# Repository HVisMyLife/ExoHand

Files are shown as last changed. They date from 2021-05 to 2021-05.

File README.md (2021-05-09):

# ExoHand
Exoskeleton build repo

IMG_4078v2

Video: https://youtu.be/7lpqHJdtj9U

I have decided few weeks ago, to design and make a prototype of an exoskeleton that would help people with disabilities in their normal functioning.
It was assumed that the designed device will support the rehabilitation of patients after elbow and hand injuries by mechanically "powering" these joints.
The design allows it to be controlled by a button in the palm of your hand, or by pre-programmed sequences of movements. It is also possible to adjust the speed via a potentiometer on the electronics housing.

List of parts:
- 12v 775 DC motor,
- MG996R servo motor,
- Blue Pill,
- 10k potentiometer,
- H 43A bridge based on half BTS7960 bridges,
- Matrix 4x4 flexible keyboard,
- 1.5mm2 cables,
- LiPo 2s 3Ah battery,
- aluminum angle 20mmx10mm,
- racks for elbow gears,
- hoops fixing the exoskeleton to the hand,
- printed elements of the hand mechanism,
- a cotton glove,
- M5 screws,
- M3 screws,
- PlastSpaw PLA 1.75mm filament

Electronic diagram:
Schematic_ExoArm

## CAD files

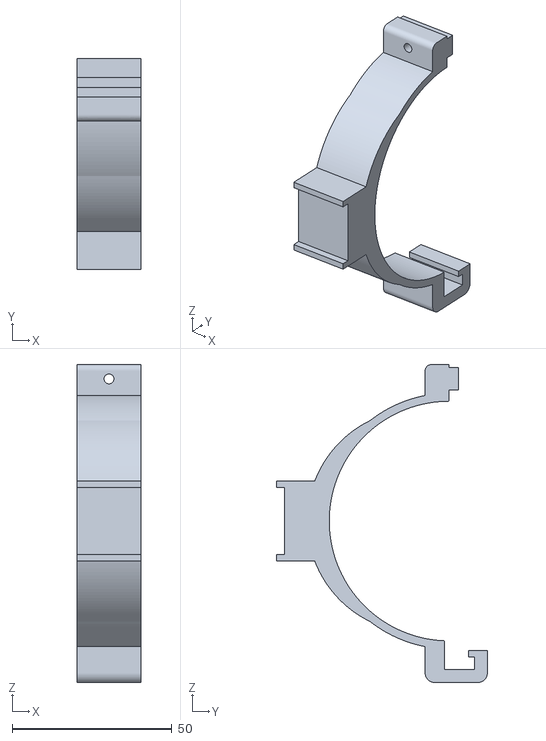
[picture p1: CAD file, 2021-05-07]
Exoskeleton/Arm/Rings/3B.stl
20.0 x 66.0 x 99.5

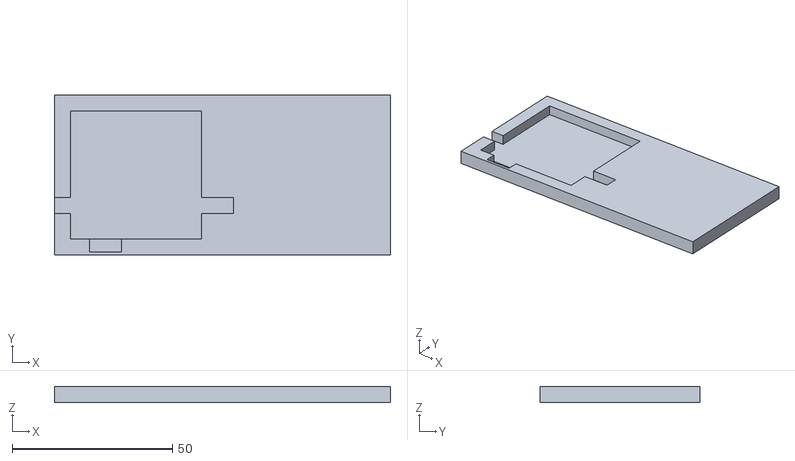
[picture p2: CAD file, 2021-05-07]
Exoskeleton/Arm/Table.stl
105.0 x 50.0 x 5.00

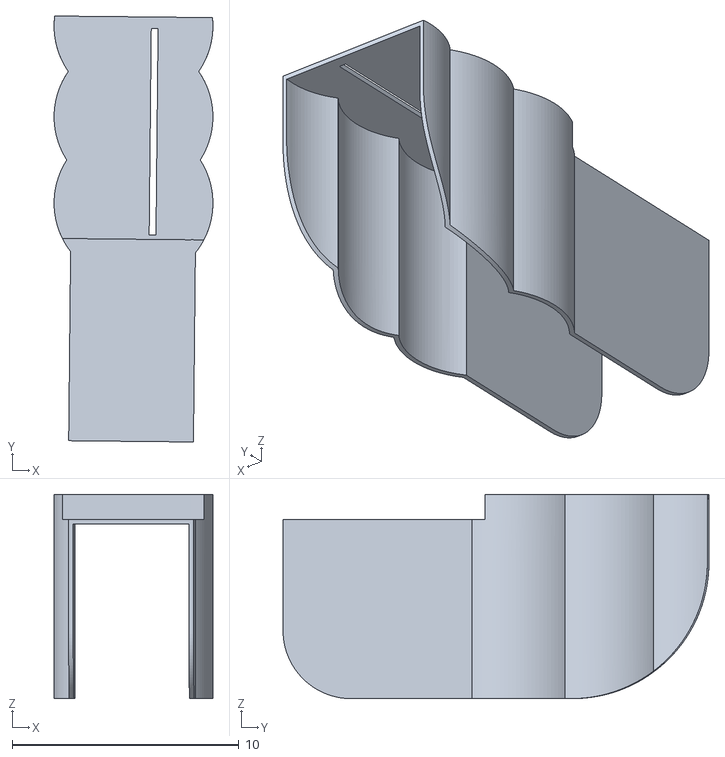
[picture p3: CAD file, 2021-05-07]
Exoskeleton/Case.stl
7.00 x 18.8 x 9.00

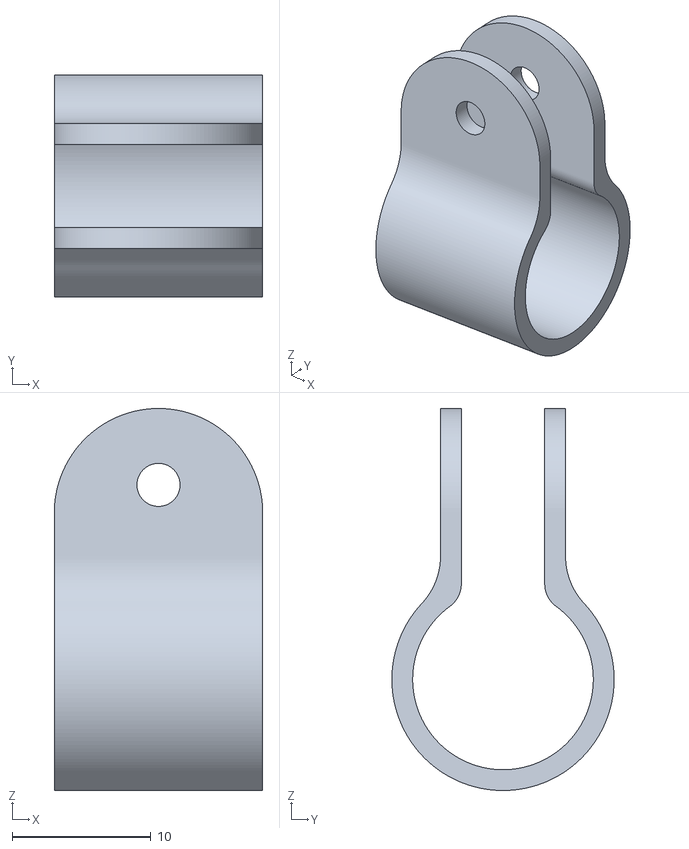
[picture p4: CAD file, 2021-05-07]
Exoskeleton/Hand/Rings/13.stl
15.0 x 16.0 x 27.5

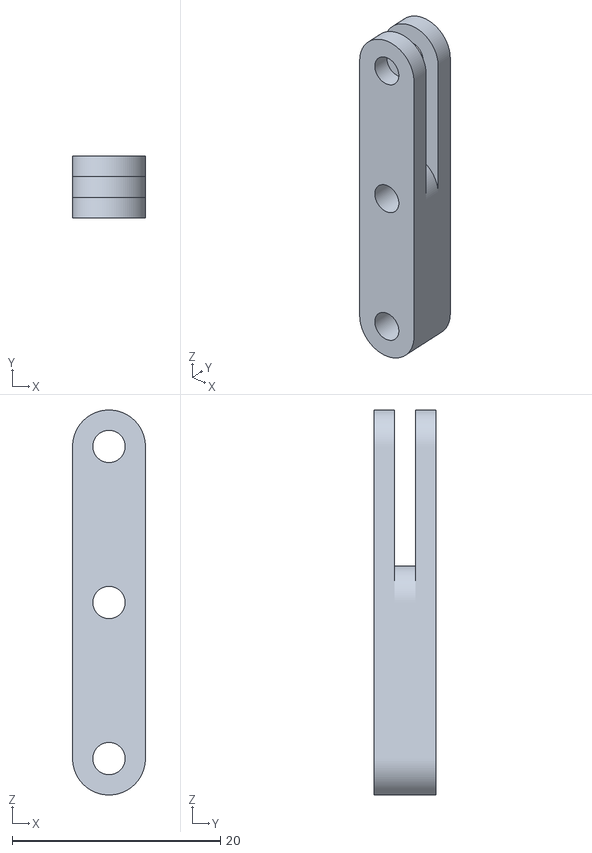
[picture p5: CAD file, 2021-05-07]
Exoskeleton/Hand/StickMid.stl
7.00 x 6.00 x 37.0

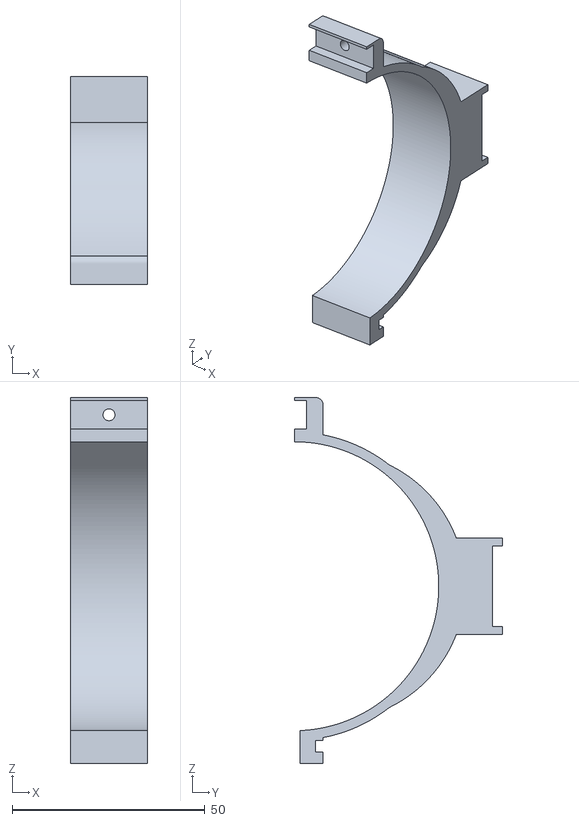
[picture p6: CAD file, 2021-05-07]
Exoskeleton/Arm/Rings/3A.stl
20.0 x 53.9 x 95.0

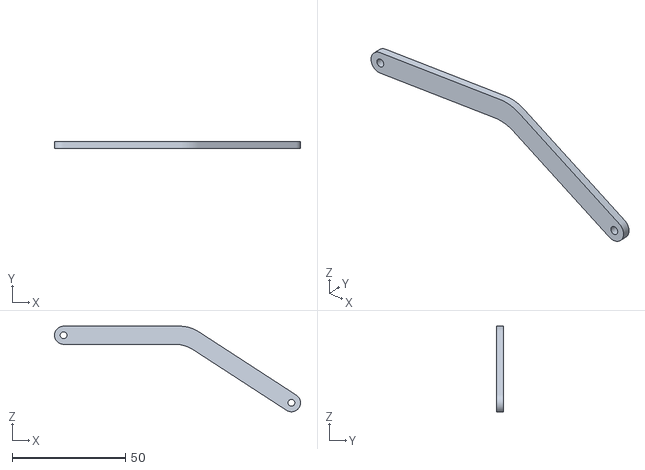
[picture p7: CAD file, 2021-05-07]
Exoskeleton/Hand/BigJoint.stl
108.8 x 3.00 x 37.8

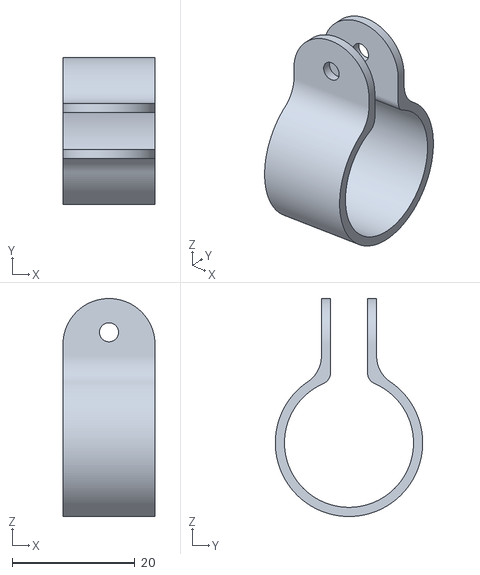
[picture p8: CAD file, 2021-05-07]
Exoskeleton/Hand/Rings/21.stl
15.0 x 24.0 x 35.5

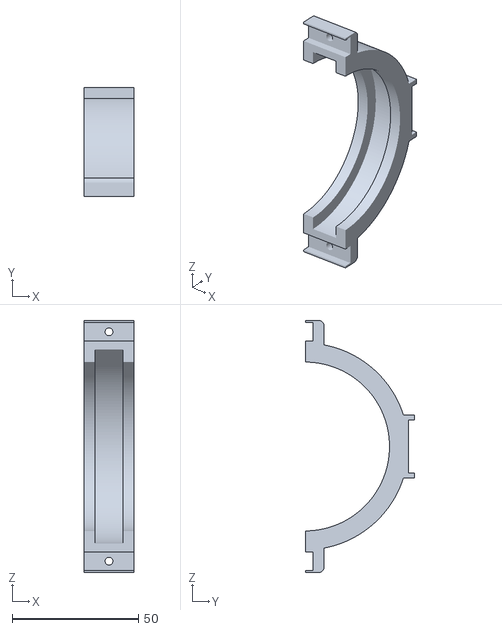
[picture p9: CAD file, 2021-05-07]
Exoskeleton/Arm/Rings/1A.stl
20.0 x 43.4 x 100.0

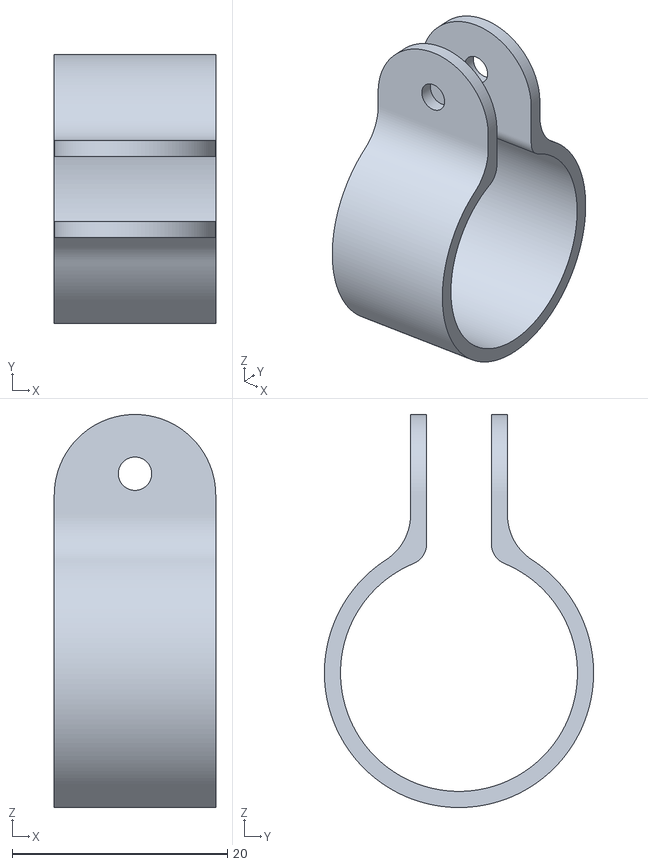
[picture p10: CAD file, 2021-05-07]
Exoskeleton/Hand/Rings/22.stl
15.0 x 25.0 x 36.5

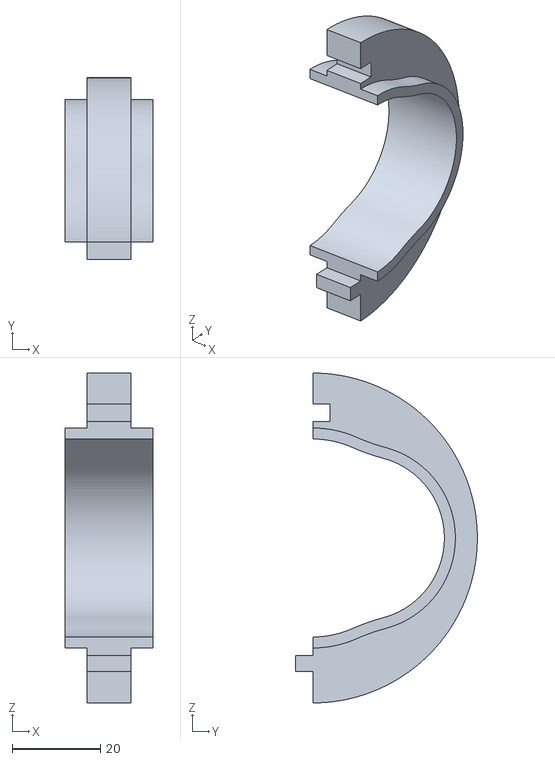
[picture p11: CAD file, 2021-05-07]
Exoskeleton/Arm/Rings/1C.stl
20.0 x 41.3 x 75.0

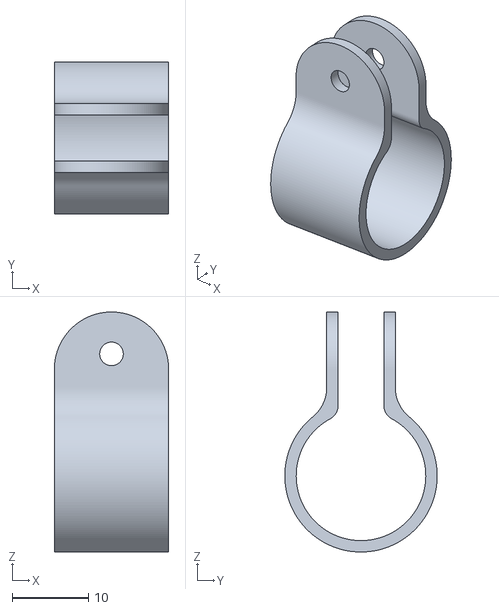
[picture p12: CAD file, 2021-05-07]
Exoskeleton/Hand/Rings/17.stl
15.0 x 20.0 x 31.5

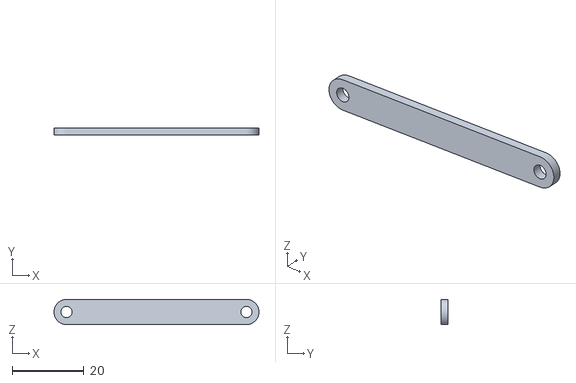
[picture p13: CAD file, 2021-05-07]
Exoskeleton/Hand/StickJoint.stl
57.0 x 2.00 x 7.00

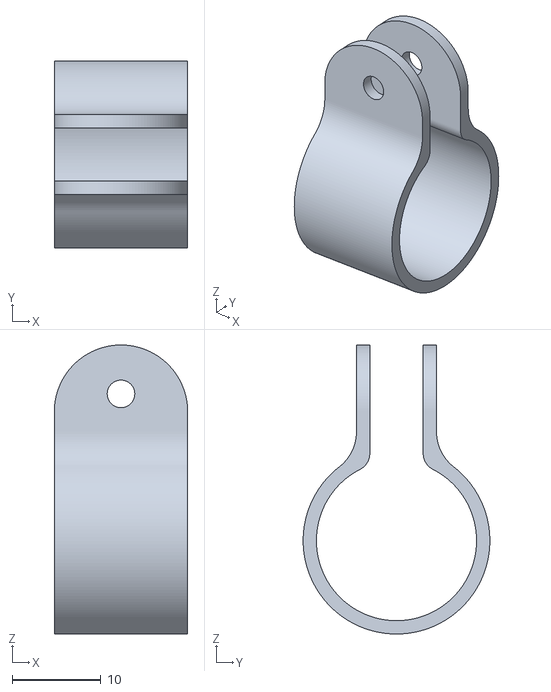
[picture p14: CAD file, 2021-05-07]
Exoskeleton/Hand/Rings/18.stl
15.0 x 21.0 x 32.5

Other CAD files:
Exoskeleton/Arm/Rings/1D.stl
Exoskeleton/Hand/StickTip.stl
Exoskeleton/Arm/Rings/2B.stl
Exoskeleton/Hand/Rings/20.stl
Exoskeleton/Arm/Rings/1B.stl
Exoskeleton/Arm/Rings/2A.stl
Exoskeleton/Arm/Rings/4A.stl
Exoskeleton/Arm/Rings/4B.stl
Exoskeleton/Hand/Bolt.stl
Exoskeleton/Hand/Rings/12.stl
Exoskeleton/Hand/Rings/14.stl
Exoskeleton/Hand/Rings/15.stl
Exoskeleton/Hand/Rings/16.stl
Exoskeleton/Hand/Rings/19.stl

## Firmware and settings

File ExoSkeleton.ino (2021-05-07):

#include <Servo.h>

int RPWM = PB9;
int LPWM = PB8;
int L_EN = PB3;
int R_EN = PB4;
int servo = PA8;

Servo hand;
float pos, armPosition;
float speedMove, speedMove2;
float pwmSig;

int pushButton = PB14;
int pot = PB1;
int potPos = PB0;
int keyPad = PA7;

int stage = 0;

int key = 0;
char keyCharBuffer;
char keyChar;
bool keyPadUsage = false, keyStartInput = false, keyStopInput = false;


bool dir, enMove = false, input;

long long unsigned int startTime, closeTime, startTime2, openTime, moveTime, keyStopTime, keyStartTime, moveDeltaTime;

void WriteMove();
void ReadPush();
void ReadKey();

void setup() {
  // put your setup code here, to run once:
  pinMode(PB9, OUTPUT);
  pinMode(PB8, OUTPUT);
  pinMode(PB3, OUTPUT);
  pinMode(PB4, OUTPUT);
  pinMode(PC13, OUTPUT);
  pinMode(pushButton, INPUT_PULLUP);
  pinMode(pot, INPUT);
  pinMode(potPos, INPUT);
  pinMode(keyPad, INPUT);

  hand.attach(servo);

  dir = true;

  digitalWrite(R_EN,HIGH);
  digitalWrite(L_EN,HIGH);
  
  delay(250);
  Serial.begin(115200);
  }

void loop() {
  WriteMove();
  ReadKey();
  ReadPush();
  
  delay(1);
}

void WriteMove()
{
  armPosition = analogRead(potPos);
  if (armPosition > 3000) armPosition = 3000;
  if (armPosition < 1500) armPosition = 1500;
  armPosition = map(armPosition, 1500, 3000, 1024, 0);
  Serial.println(armPosition);
  //Serial.print(" || ");
  //Serial.println(pos);
  speedMove = map(analogRead(pot), 0, 4096, 0, 1000);

  pwmSig = armPosition - pos;
  if (pwmSig < 0) pwmSig = -pwmSig;
  if (pwmSig > 255) pwmSig = 255;
  speedMove2 = map(speedMove, 0, 1000, 400, 75);
  speedMove2 /= 100;
    
  if(enMove && armPosition > 0 && dir) 
  {
    if( micros() - moveDeltaTime > speedMove) { pos -= speedMove2; moveDeltaTime = micros();}
    if (pos < 0) pos = 0;
    hand.write(map(pos, 0, 1024, 0, 255));
    if(armPosition > pos + 25) {analogWrite(LPWM, pwmSig); analogWrite(RPWM, 0);}
    else if(armPosition < pos - 25) {analogWrite(LPWM, 255); analogWrite(RPWM, 255);}
    else {analogWrite(LPWM, 0);analogWrite(RPWM, 0);}
  }
  else if (enMove && armPosition < 1024 && !dir) 
  {
    if( micros() - moveDeltaTime > speedMove ) { pos += speedMove2; moveDeltaTime = micros();}
    if (pos > 1024) pos = 1024;
    hand.write(map(pos, 0, 1024, 0, 255));
    if(armPosition < pos - 25) {analogWrite(LPWM, 0); analogWrite(RPWM, pwmSig);}
    else if(armPosition > pos + 25) {analogWrite(LPWM, 255); analogWrite(RPWM, 255);}
    else {analogWrite(LPWM, 0);analogWrite(RPWM, 0);}
  }
  else
  {
    analogWrite(LPWM, 0);
    analogWrite(RPWM, 0);
  }

  //if ( armPosition <= 50 && dir && enMove || armPosition >= 1998 && !dir && enMove ) {stage = 0; enMove = false;}
}

void ReadPush()
{
  input = digitalRead(pushButton);
  digitalWrite(PC13, input);
   
  switch (stage){
    case 0:
      if ( !input ) {startTime = millis(); stage = 1;}
    break;
    case 1:
      if (input && millis() - startTime < 100) stage = 0;
      else if (!input && millis() - startTime >= 100) stage = 2;
    break;
    case 2:
      if (input) {startTime2 = millis(); stage = 3; }
    break;
    case 3:
      if (!input && millis() - startTime2 < 50) stage = 2;
      else if (!input && millis() - startTime2 >= 50) stage = 4;                              //double
      else if (input && millis() - startTime2 >= 750) { stage = 5; enMove = true; dir = false; moveTime = millis(); moveDeltaTime = micros();}   //single
    break;
    case 4:
      if (input) { stage = 5; enMove = true; dir = true; moveTime = millis(); moveDeltaTime = micros();}
    break;
    case 5:
      if (!input && millis() - moveTime > 25) {stage = 6; enMove = false;}
    break;
    case 6:
      if (input) stage = 0;
    break;
    default:
      
    break;
  }
}

void ReadKey()
{
  key = ((key * 19) + analogRead(keyPad)) / 20;
  //key = analogRead(keyPad);
  
  if (key < 100) keyCharBuffer = 'X';
  else if (key < 220) keyCharBuffer = '*';
  else if (key < 235 ) keyCharBuffer = '0';
  else if (key < 250 ) keyCharBuffer = '#';
  else if (key < 270 ) keyCharBuffer = 'D';
  else if (key < 305 ) keyCharBuffer = '7';
  else if (key < 330 ) keyCharBuffer = '8';
  else if (key < 360 ) keyCharBuffer = '9';
  else if (key < 400 ) keyCharBuffer = 'C';
  else if (key < 490 ) keyCharBuffer = '4';
  else if (key < 550 ) keyCharBuffer = '5';
  else if (key < 650 ) keyCharBuffer = '6';
  else if (key < 800 ) keyCharBuffer = 'B';
  else if (key < 1100 ) keyCharBuffer = '1';
  else if (key < 1700 ) keyCharBuffer = '2';
  else if (key < 3000 ) keyCharBuffer = '3';
  else  keyCharBuffer = 'A';

  if ( keyCharBuffer != 'X' && !keyStartInput && !keyPadUsage) { keyStartTime = millis(); keyStartInput = true;}
  else if ( keyStartInput && millis() - keyStartTime > 100 && !keyPadUsage ) { keyPadUsage = true; keyStartInput = false; keyChar = keyCharBuffer;}
  else if ( keyStartInput && keyCharBuffer == 'X' ) keyStartInput = false;
  else if ( keyCharBuffer == 'X' && keyPadUsage && !keyStopInput) { keyStopTime = millis(); keyStopInput = true; }
  else if ( keyStopInput && millis() - keyStopTime > 100 && keyPadUsage ) { keyPadUsage = false; keyStopInput = false; }
  else if ( keyStopInput && keyCharBuffer != 'X' ) keyStopInput = false;
  
  if ( !keyPadUsage ) keyChar = 'X';
  
  //Serial.println(keyChar);
}
